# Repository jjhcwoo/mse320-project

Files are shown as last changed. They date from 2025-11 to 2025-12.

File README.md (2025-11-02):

# MSE 320 - Machine Design
**Project: Merry-Go-Round**

**Group 13**

The objective of this project is to design and develop a safe, mechanical merry-go-round, intended for children aged six and under. The purpose of this project is to create a functional and reliable design that encourages outdoor physical activity, supporting healthy child development. 

## Members

Justin Woo - 301301003

Kevin Hagerty - 301590072

Kazuki Kung - 301598637

Matias del Rio Reategui - 301578678

Ali Maleki-Rizi - 301594477

## Tasklist

https://docs.google.com/spreadsheets/d/1anBV4Q--yBRxReo88BjWod1RGUA-kIAJZquwBPfQGeU/edit?usp=sharing

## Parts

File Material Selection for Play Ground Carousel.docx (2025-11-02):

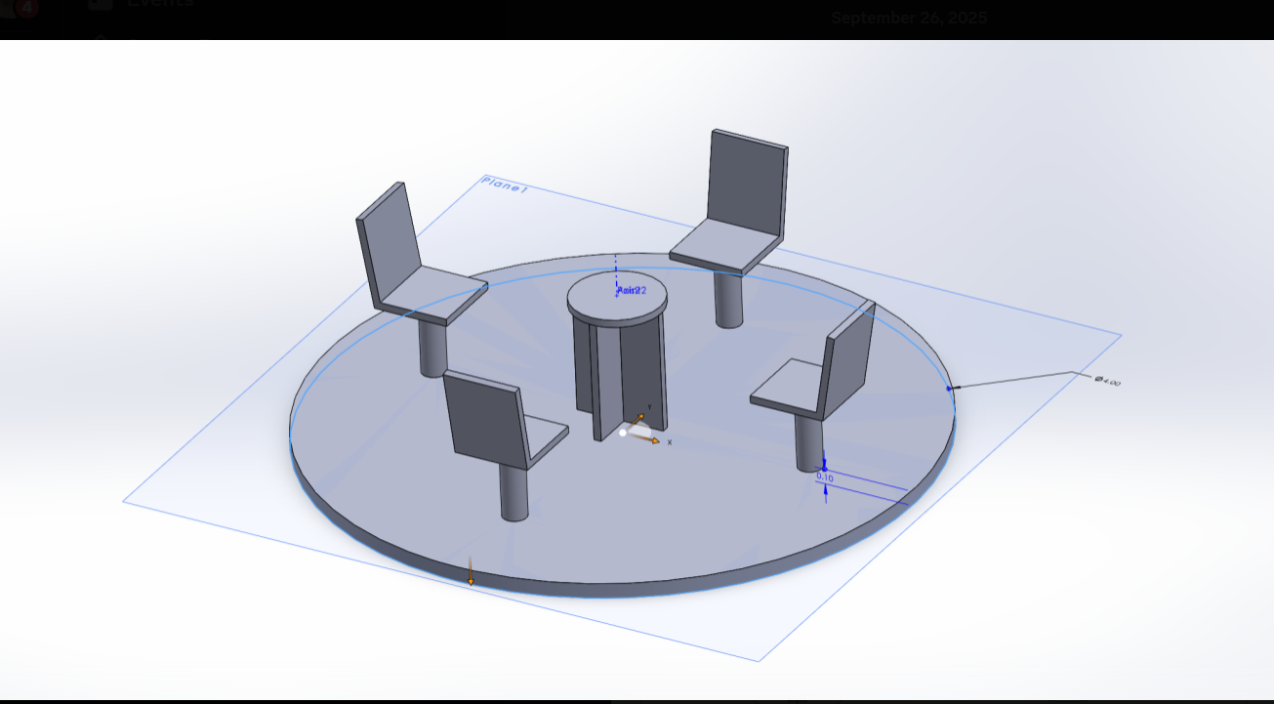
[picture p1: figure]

Overview:

Using the image above as reference, we are looking to select ideal materials for our playground carousel. The criteria for the selection is that the materials must be safe, durable, cost effective, and hopefully easy to manipulate for assembly. Our carousel consists of a circular base plate with four seats on top that will be bearing a 200N load and a centripetal load when in use.

Material options:

Part | Material | Pros | Cons | Score (0-10)
Base Plate | Carbon Steel (AISI 1020) | - Stiff and tough for the price( E= 200 GPa) - Easy to weld - Simple fabrication - Takes HDG (hot dip galvanization) and powder coat for a longer outdoor life | - Needs HDG and powder for corrosion protection - Heavier that aluminum, harder to move/ install | 9
| Aluminum Plate (Aluminum 5052-H32) | - Lightweight - Good corrosion resistance without coatings | - Lower stiffness ( 69 GPa) meaning we need a greater thickness - Costlier p kg than steel - Harder to weld | 5
| Stainless steel Plate (AISI 304/316) | - Very good corrosion resistance - No need for paint (low maintenance) - Good toughness and easy to weld | - Very expensive - Heavier than carbon steel | 7
Seat post | Plain Carbon Steel (AISI 1020) | - Great against buckling - Very weldable - Takes HDG (hot dip galvanization) and powder coat for a longer outdoor life | - Needs HDG and powder for corrosion protection - Heavier that aluminum, harder to move/ instal | 9
| Stainless steel | - Very good corrosion resistance - No need for paint (low maintenance) - Good toughness and easy to weld | - Very expensive - Heavier than carbon steel | 8
| Aluminum Tube (6061-T6) | - Lightweight | - Lower stiffness - Needs thicker wall to meet buckling limit | 4
Seats | High Density Poly Ethalyne (HDPE) | - Non-splintering - Easily round edges - Warm to touch - UV/ weather resistant with no added paint - High impact toughness - Low maintenance - inexpensive | - Lower stiffness vs metals - Creep under high | 9
| Phenolic Laminate (HPL) | - Very stiff, thinner than HDPE for same feel - Weather resistant without paint or coat | - Edges are harder - Brittle compared to HDPE with sharp impacts - More expensive than HDPE | 6
| Aluminum 5052-H32 | - Lightweight - Easy to pass ribs or beads for stiffness | - Hot to touch under sun - Slippery unless textured - Needs extra work around sharp edges - High fabrication effort | 6
Floor | Aluminum 5052-H32 Tread (Checker) | - Great wet traction - Corrosion resistant - Lightweight | - Thermal comfort | 8
| Fiberglass (GFRP ) | - Excellent wet/dry traction - Thermal comfort - Good impact toughness | - Brittle edges - UV topcoat - higher cost compared to aluminum | 7

Materials:

Part | Material | Reason for Selection
Base Plate | Carbon Steel (AISI 1020)
Seat post | Carbon Steel (AISI 1020)
Seat | HDPE
Floor plate | Aluminum 5052-H32 Tread (Checker)

References:

- https://cemer.com/en/carousels
- https://www.miracle-recreation.com/blog/different-playground-equipment-surfaces/?lang=can
- Solidworks
- https://www.cpsc.gov/s3fs-public/325.pdf?utm_
- https://www.polymershapes.com/application/playground-equipment/

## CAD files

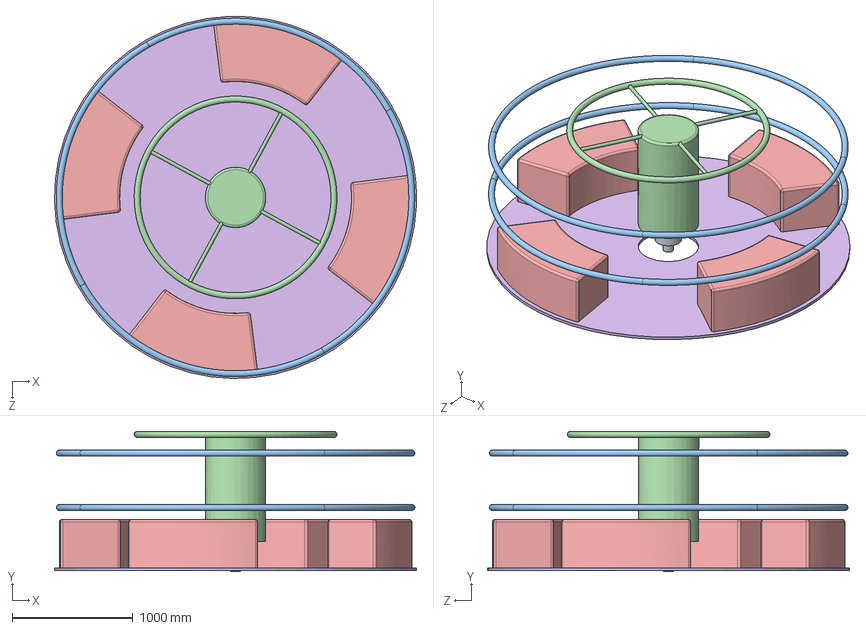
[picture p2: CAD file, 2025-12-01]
test.SLDASM
2998.4 x 1161.0 x 2998.3 mm
Baseplate
Seat Block x 4
Shaft
Horizontal Bar x 8
axel to gearbox
bottom

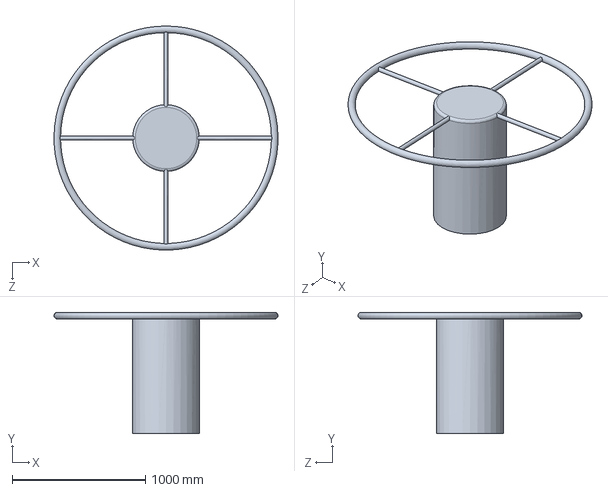
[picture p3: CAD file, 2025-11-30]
References/Shaft.SLDPRT
1679.6 x 910.0 x 1679.2 mm

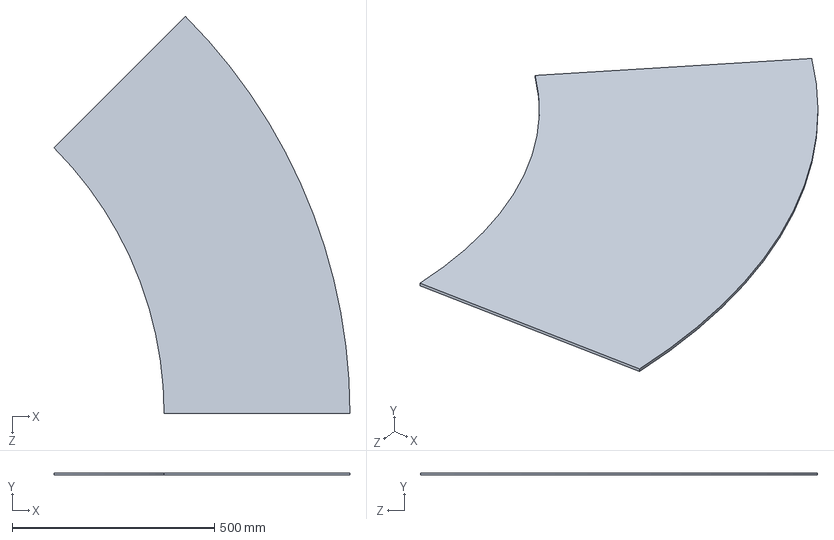
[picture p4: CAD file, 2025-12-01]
Seat.SLDPRT
732.4 x 5.00 x 982.9 mm

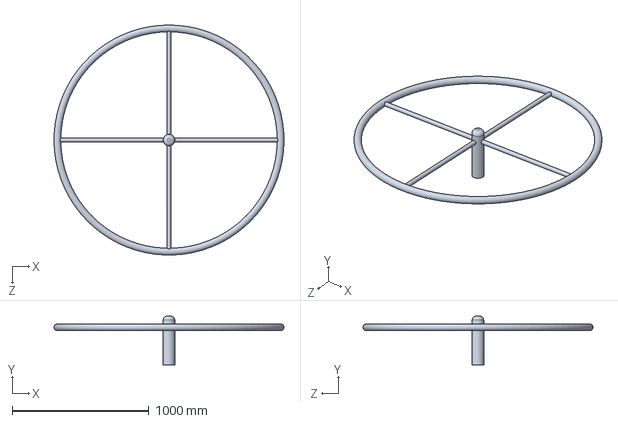
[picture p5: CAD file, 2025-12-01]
Shaft.SLDPRT
1679.6 x 357.0 x 1679.3 mm

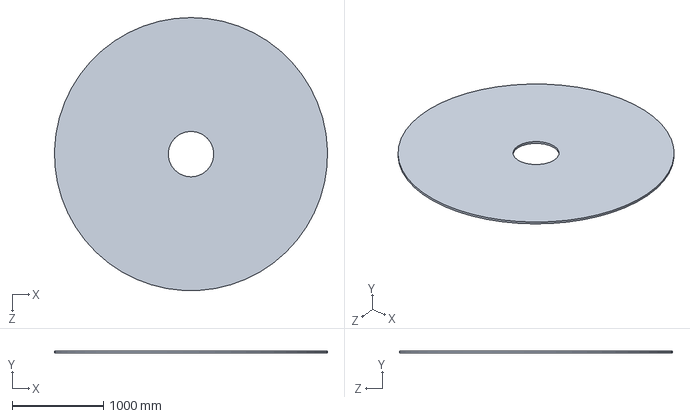
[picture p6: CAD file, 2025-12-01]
Baseplate.SLDPRT
2998.7 x 23.0 x 2997.4 mm

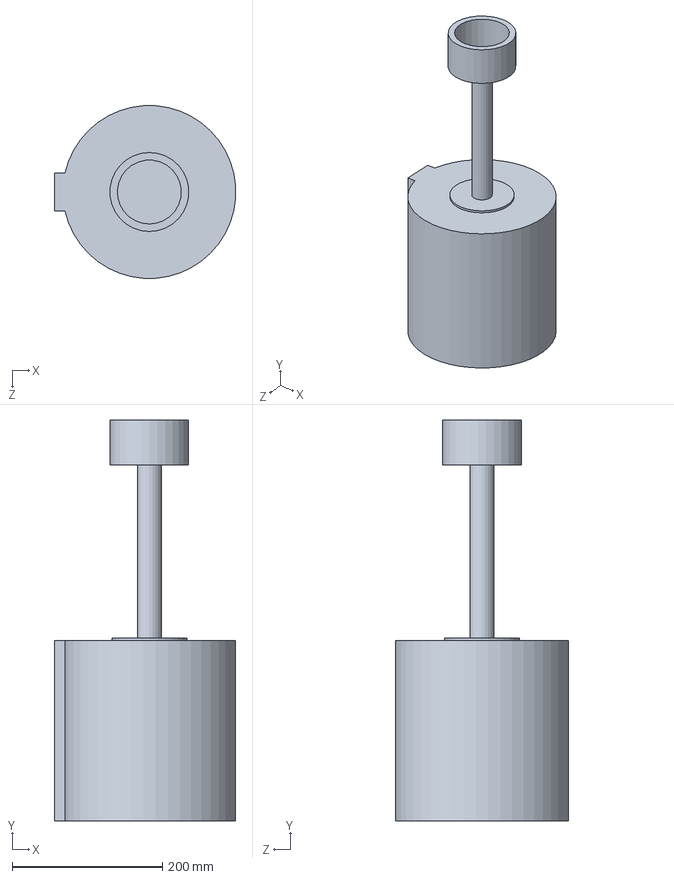
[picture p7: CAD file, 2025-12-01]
axel to gearbox.SLDPRT
241.0 x 533.0 x 229.5 mm

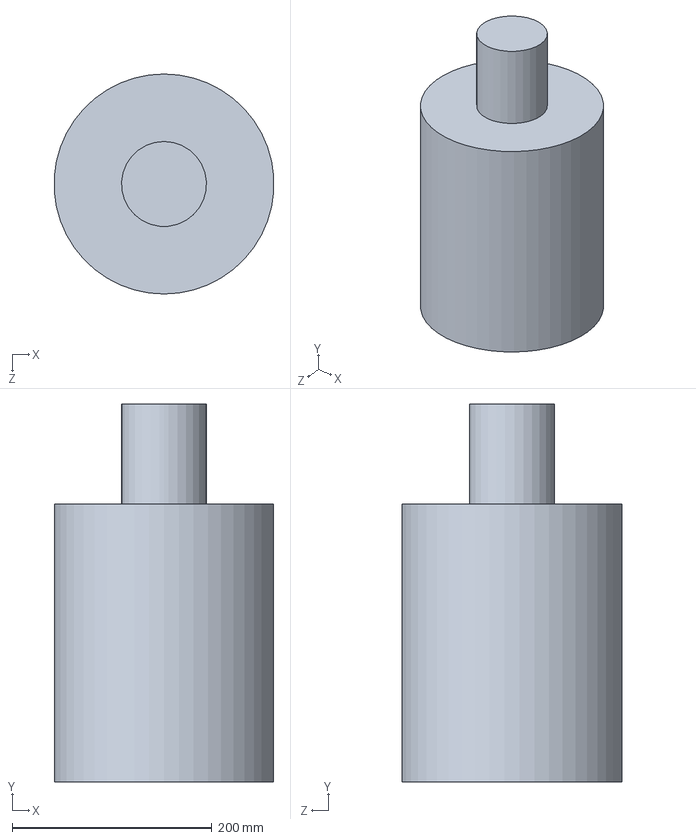
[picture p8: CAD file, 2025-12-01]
bottom.SLDPRT
219.5 x 378.0 x 220.0 mm

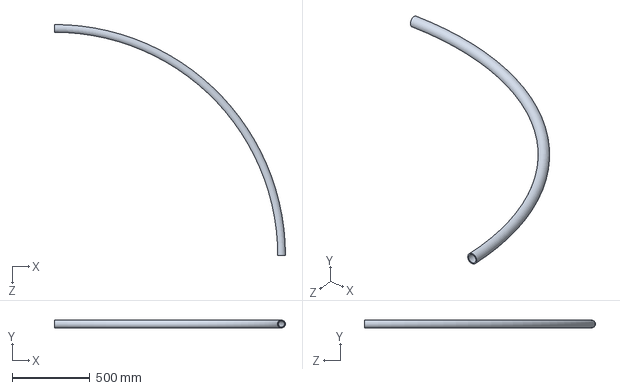
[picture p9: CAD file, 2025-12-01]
Horizontal Bar.SLDPRT
1485.0 x 50.0 x 1485.0 mm

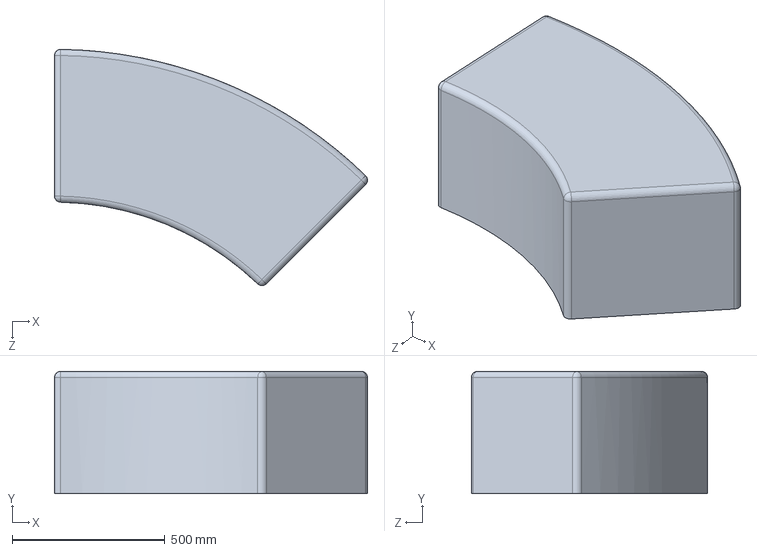
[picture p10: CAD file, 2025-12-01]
Seat Block.SLDPRT
1023.9 x 400.0 x 772.9 mm

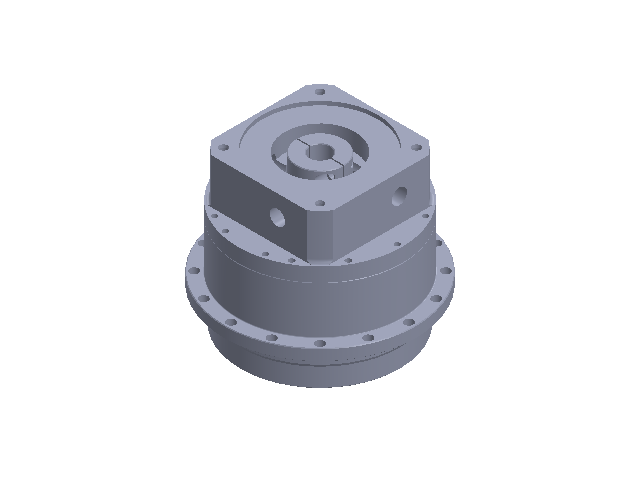
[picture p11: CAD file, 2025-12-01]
Gear box/planetary_gearbox_bdb_300_-_ratio_4.SLDASM
planetary_gearbox_bdb_300_-_ratio_4_01
planetary_gearbox_bdb_300_-_ratio_4_02
planetary_gearbox_bdb_300_-_ratio_4_03
planetary_gearbox_bdb_300_-_ratio_4_04
planetary_gearbox_bdb_300_-_ratio_4_05
planetary_gearbox_bdb_300_-_ratio_4_06

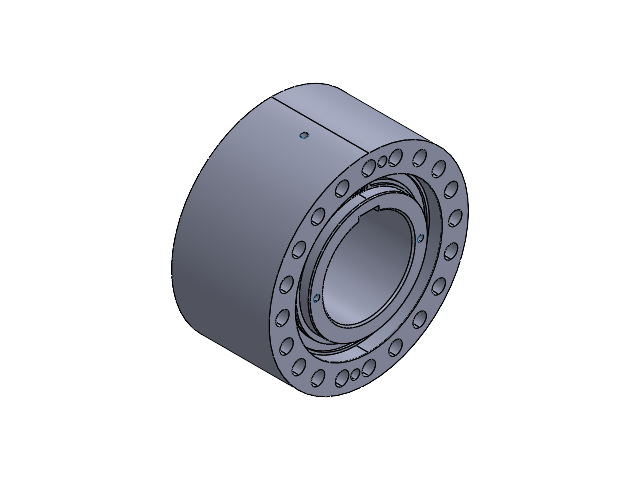
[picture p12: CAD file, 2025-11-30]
Sprag clutch/RSCI_180-300220_II-M.SLDASM
SCHEIBE_RSCI_220IIM_3_NICO_1_1.stp x 2
KLEMMKOERPER_KA35B_62_1_1.stp x 8
BOLZEN_KA35_63_9_1_1.stp x 8
SCHEIBE_RSCI_220IIM_7_NICO_1_1.stp x 2
MITNEHMER_RSBI_150A_NICO_1_1.stp x 4
ISO2009-M5X10-8_8-HD_1_1.stp x 8
I-RING_RSCI_220IIM_NICO_1_1.stp
DIN471_290X5_HD_1_1.stp x 4
A-RING_RSCI_220IIM_1_1.stp

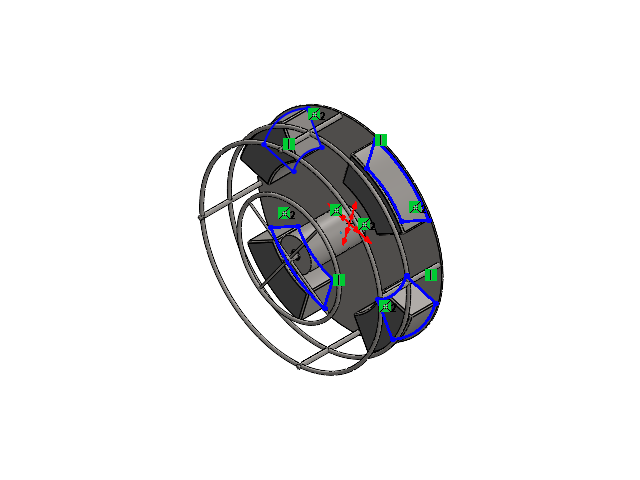
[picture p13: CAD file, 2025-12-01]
Assembly.SLDASM
Baseplate
SCHEIBE_RSCI_220IIM_3_NICO_1_1.stp x 2
KLEMMKOERPER_KA35B_62_1_1.stp x 8
BOLZEN_KA35_63_9_1_1.stp x 8
SCHEIBE_RSCI_220IIM_7_NICO_1_1.stp x 2
MITNEHMER_RSBI_150A_NICO_1_1.stp x 4
ISO2009-M5X10-8_8-HD_1_1.stp x 8
I-RING_RSCI_220IIM_NICO_1_1.stp
DIN471_290X5_HD_1_1.stp x 4
A-RING_RSCI_220IIM_1_1.stp
planetary_gearbox_bdb_300_-_ratio_4_01
planetary_gearbox_bdb_300_-_ratio_4_02
planetary_gearbox_bdb_300_-_ratio_4_03
planetary_gearbox_bdb_300_-_ratio_4_04
planetary_gearbox_bdb_300_-_ratio_4_05
planetary_gearbox_bdb_300_-_ratio_4_06
hole
2349K758_Permanently Lubricated Ball Bearing x 2
Shaft
axel to gearbox
bottom
Seat Block x 4
Vertical Bar x 4
Horizontal Bar x 8
Seat x 4

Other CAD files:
Gear box/planetary_gearbox_bdb_300_-_ratio_4_01.SLDPRT
Gear box/planetary_gearbox_bdb_300_-_ratio_4_05.SLDPRT
Gear box/planetary_gearbox_bdb_300_-_ratio_4_06.SLDPRT
Gear box/planetary_gearbox_bdb_300_-_ratio_4_02.SLDPRT
Gear box/planetary_gearbox_bdb_300_-_ratio_4_03.SLDPRT
Gear box/planetary_gearbox_bdb_300_-_ratio_4_04.SLDPRT
2349K758_Permanently Lubricated Ball Bearing.SLDPRT
Vertical Bar.SLDPRT
hole.SLDPRT

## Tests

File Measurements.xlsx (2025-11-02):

Name | Age | Sitting Height (foot to head) | Arm Length (back to fingertips) | Leg Length (leg to hip standing)
Willow (F) | 5 | 99 | 49 | 62
Ryan (M) | 6 | 102 | 56 | 63
Evander (M) | 6 | 104 | 52 | 73

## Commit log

2025-11-02 Add initial SolidWorks files
    Upload initial SolidWorks and auxiliary files from project. Project references put into "Reference" folder.
    [Assembly.SLDASM, Backing.SLDPRT, Baseplate.SLDPRT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]
2025-11-03 Update SolidWorks files
    - change dimensions of supporting bars
    - added seat blocks for easier modelling
    - reduced seat cover thickness
    [Assembly.SLDASM, Backing.SLDPRT, Baseplate.SLDPRT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]
2025-11-30 Add mechanism and refinements
    - Add mechanism parts into assembly
    - Adjust previous part files to decrease mass and include filets
    [2349K758_Permanently Lubricated Ball Bearing.SLDPRT, Assembly.SLDASM, Baseplate.SLDPRT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]
2025-12-01 Modify files for Static Analysis
    - Run static analysis on test.SLDASM
    - Finalize parts for project
    [Assembly.SLDASM, Backing.SLDPRT, Baseplate.SLDPRT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]
